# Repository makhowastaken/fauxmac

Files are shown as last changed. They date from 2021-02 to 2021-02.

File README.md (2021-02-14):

# fauxmac
Romac+ Macro Pad remade because the original is no longer for sale

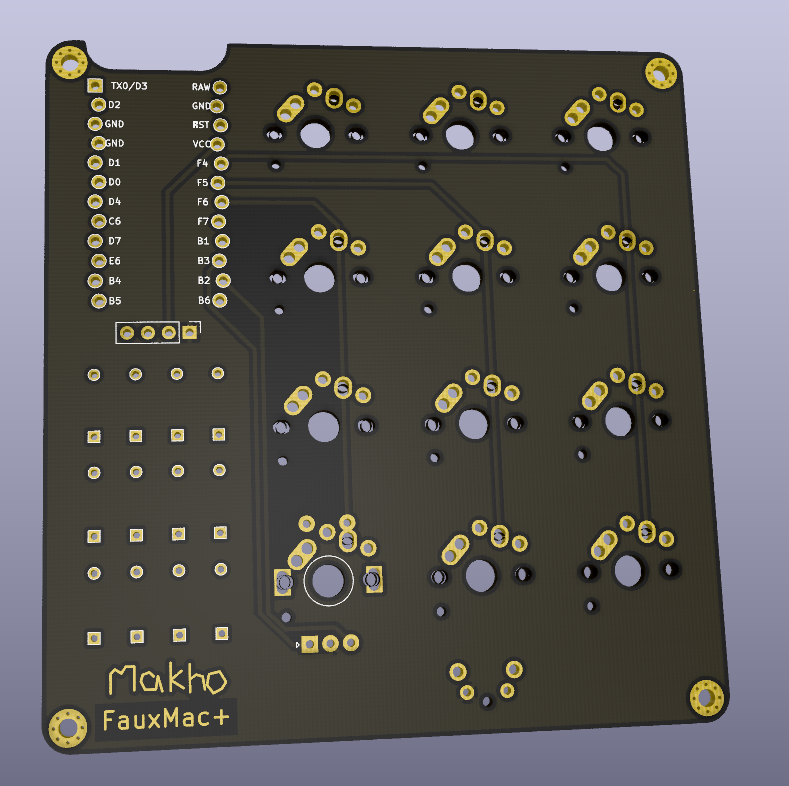
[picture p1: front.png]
front


It should use the same firmware as the official QMK repo Romac+ but things may have to be tweaked slightly. Uses a LED strip instead of four SMT RGB LEDs soldered to the bottom. You can use as many as you want but make sure to tweak the firmware if you use more than four. 

Case sizing IS different. I don't know what the original is sized at but mine is sized 83.8mm wide by 88.0mm tall. Mounting hole spacing is 77.8mm wide by 82.0mm tall. Key spacing is 19.0mm 

I exported the board to a SVG to assist with case design

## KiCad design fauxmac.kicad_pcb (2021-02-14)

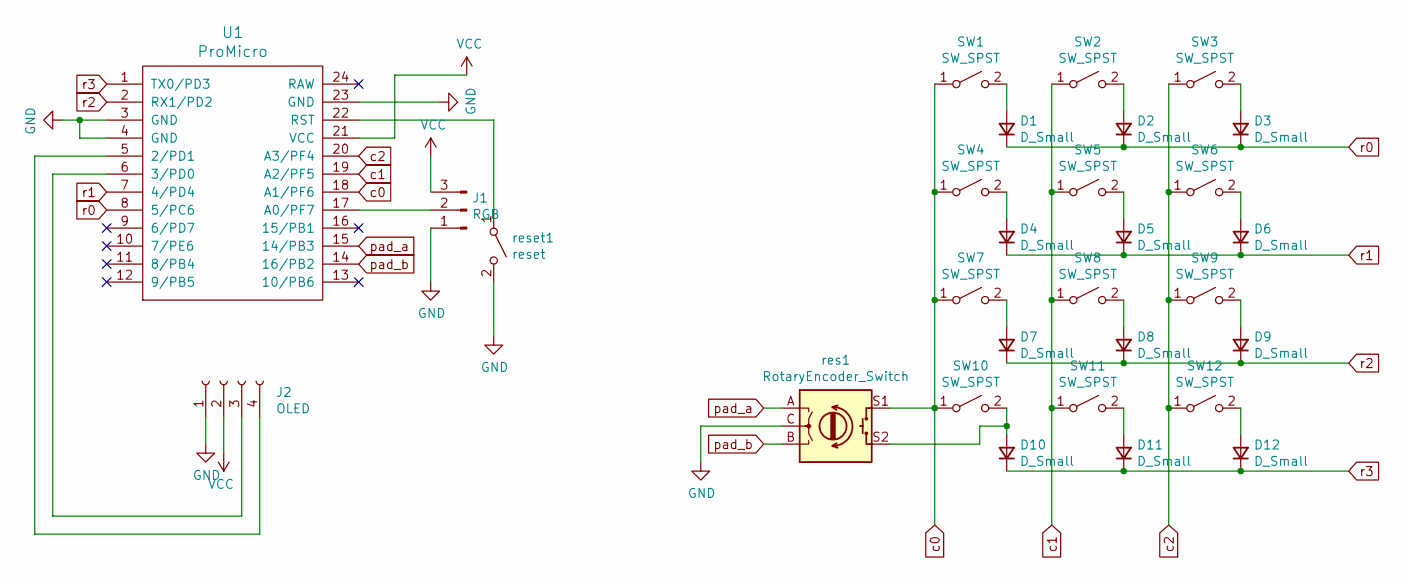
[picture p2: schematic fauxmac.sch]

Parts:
D1, D2, D3, D4, D5, D6, D7, D8, D9, D10, D11, D12: D_Small; D3_TH_SMD_back_only
J1: RGB; StripLED_rev_frontonly
J2: OLED; PinHeader_1x04_P2.54mm_Vertical
SW1, SW2, SW3, SW4, SW5, SW6, SW7, SW8, SW9, SW10, SW11, SW12: SW_SPST; MX-Alps-Choc-1U-NoLED
U1: ProMicro; ArduinoProMicro-ZigZag_back_silk_removed
res1: RotaryEncoder_Switch; RotaryEncoder_EC11
reset1: reset; SW_Tactile_SPST_Angled_MJTP1117

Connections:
GND: J1.1, J2.1, U1.3 (GND), U1.4 (GND), U1.23 (GND), res1.C, reset1.2 (B)
unnamed: D1.2 (A), SW1.2 (B)
unnamed: D2.2 (A), SW2.2 (B)
unnamed: D3.2 (A), SW3.2 (B)
unnamed: D4.2 (A), SW4.2 (B)
unnamed: D5.2 (A), SW5.2 (B)
unnamed: D6.2 (A), SW6.2 (B)
unnamed: D7.2 (A), SW7.2 (B)
unnamed: D8.2 (A), SW8.2 (B)
unnamed: D9.2 (A), SW9.2 (B)
unnamed: D10.2 (A), SW10.2 (B), res1.S2
unnamed: D11.2 (A), SW11.2 (B)
unnamed: D12.2 (A), SW12.2 (B)
unnamed: J1.2, U1.17 (A0/PF7)
unnamed: J2.3, U1.6 (3/PD0)
unnamed: J2.4, U1.5 (2/PD1)
unnamed: U1.22 (RST), reset1.1 (A)
VCC: J1.3, J2.2, U1.21 (VCC)
c0: SW1.1 (A), SW4.1 (A), SW7.1 (A), SW10.1 (A), U1.18 (A1/PF6), res1.S1
c1: SW2.1 (A), SW5.1 (A), SW8.1 (A), SW11.1 (A), U1.19 (A2/PF5)
c2: SW3.1 (A), SW6.1 (A), SW9.1 (A), SW12.1 (A), U1.20 (A3/PF4)
pad_a: U1.15 (14/PB3), res1.A
pad_b: U1.14 (16/PB2), res1.B
r0: D1.1 (K), D2.1 (K), D3.1 (K), U1.8 (5/PC6)
r1: D4.1 (K), D5.1 (K), D6.1 (K), U1.7 (4/PD4)
r2: D7.1 (K), D8.1 (K), D9.1 (K), U1.2 (RX1/PD2)
r3: D10.1 (K), D11.1 (K), D12.1 (K), U1.1 (TX0/PD3)

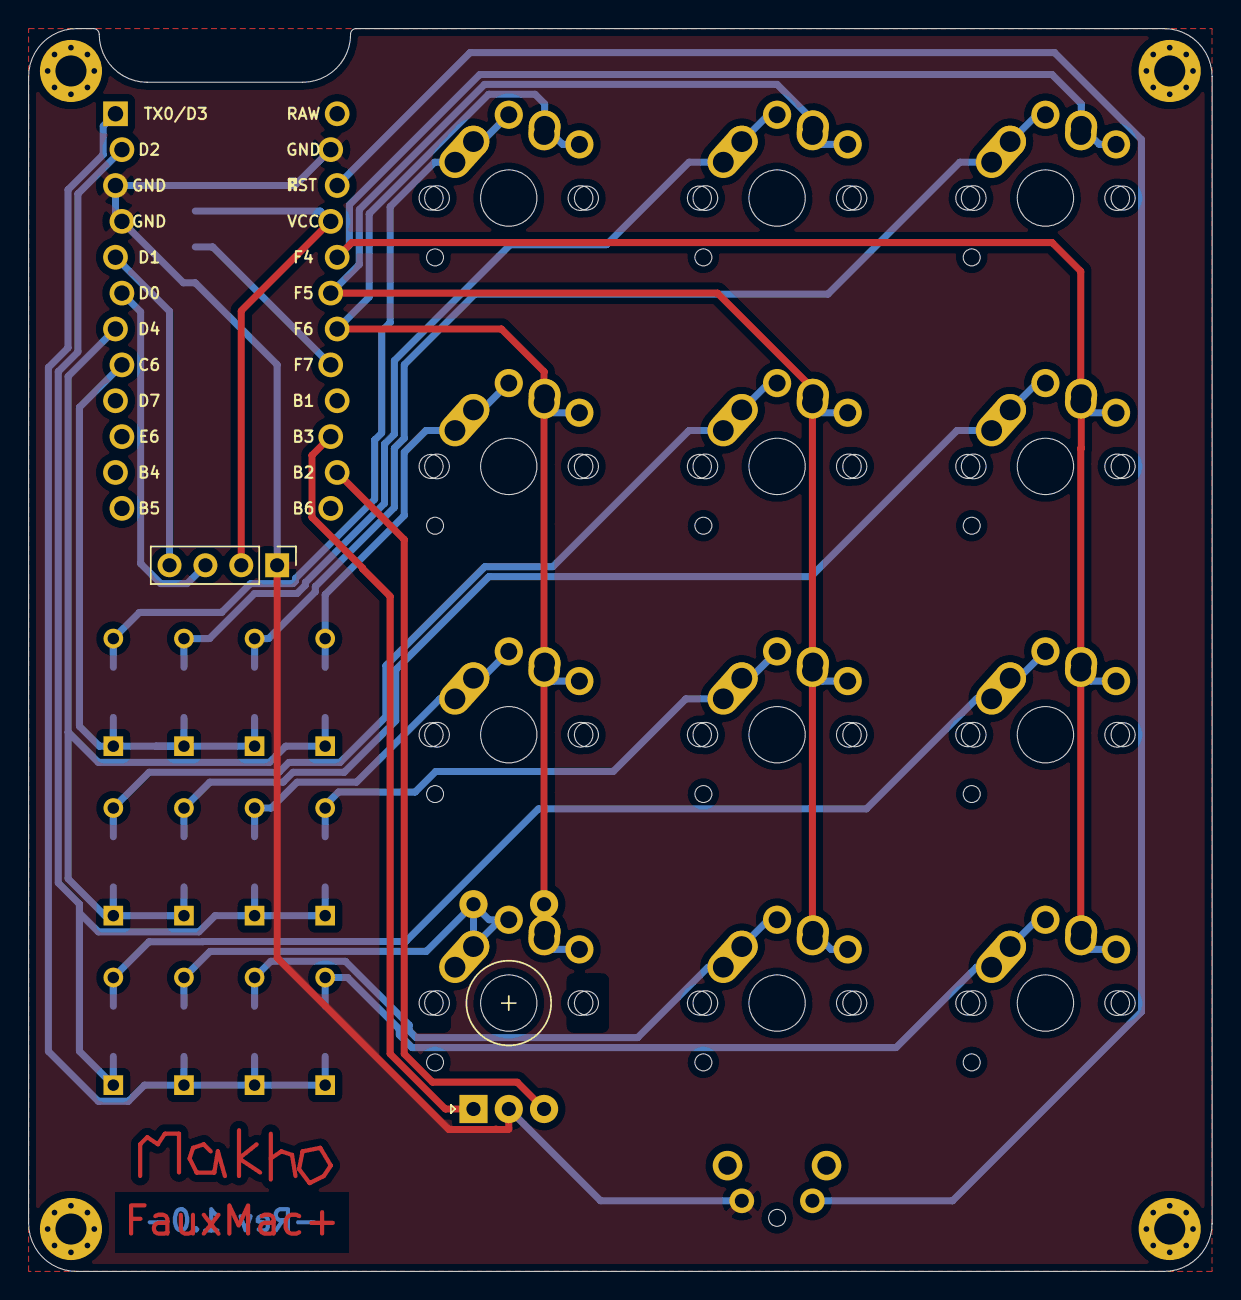
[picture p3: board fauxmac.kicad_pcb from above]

Board: 2 copper layers, 83.8 x 88.0 mm, 29 parts (1 on the bottom side), 27 nets.
